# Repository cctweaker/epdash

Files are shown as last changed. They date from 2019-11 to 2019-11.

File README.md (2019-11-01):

# epdash
ESP8266 + E-paper wireless dashboard

It is a complete project, from 3D design to microcontroller program and webserver helper.

Main components are:
- the e-paper display: Waveshare 7.5 black/red display => https://www.waveshare.com/wiki/7.5inch_e-Paper_HAT_(B)
- trigBoard from Kevin Darrah: https://www.kevindarrah.com/wiki/index.php?title=TrigBoard
- EPaperBoard also from Kevin Darrah: https://www.kevindarrah.com/wiki/index.php?title=EPaperBoard
- 2 pcs. Li-Ion batteries 3500mAh each that should power this device for quite some time

Trigboard is a ESP8266 ultra low power standby device. It wakes up and powers the ESP and display and then goes back to ULP sleep. The timer can be programmed by changing a resistor and I chose one that wakes up the device once every ~30 minutes.

After waking up, the ESP connects to a intranet web server and fetches a 640x384 pixel bmp file that it then displays. After finishing, it signals the timer chip that it is done and power is removed. Countdown of a new sleep period begins.

My goal was a complete freedom to setup the display. Using the ESP to generate the display data meant always changing the programming on the chip, updating its flash and so on. Pretty cumbersome. Moving the display data creation to a local webserver and fetching just the bmp file allowed me change anything at any time, without bothering the display unit itself.

Initial project was a weather display. Data was retreived by json and set up on the ESP, total time to update the display was about 300 seconds. Now I serve just the bmp file, generated on the fly, and the update time was reduced to about 55 seconds with DHCP enabled on the ESP. Probably a few seconds less by manually assigning the IP address.

Sample output:<br>
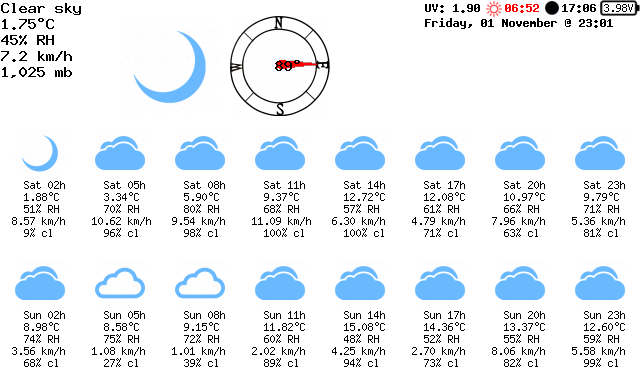
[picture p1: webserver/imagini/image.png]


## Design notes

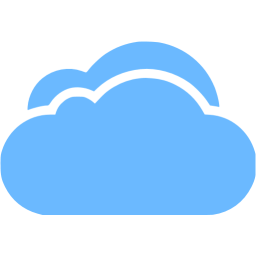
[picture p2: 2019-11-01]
webserver/meteo/04n.png

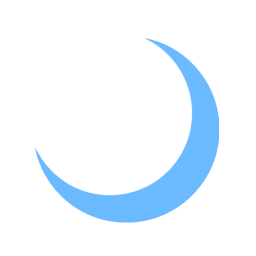
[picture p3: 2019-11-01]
webserver/meteo/01n.png

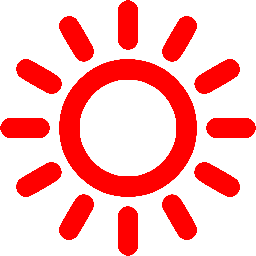
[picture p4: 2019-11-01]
webserver/meteo/01d.png

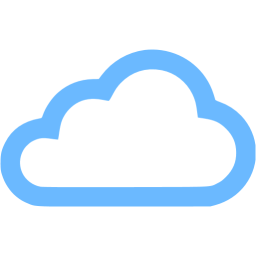
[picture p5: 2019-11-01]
webserver/meteo/03n.png

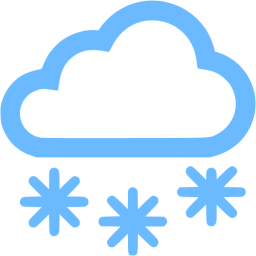
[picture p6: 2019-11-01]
webserver/meteo/13n.png

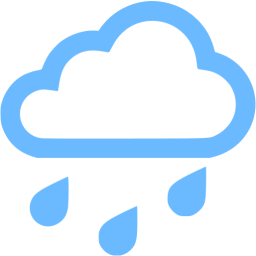
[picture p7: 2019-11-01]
webserver/meteo/09n.png

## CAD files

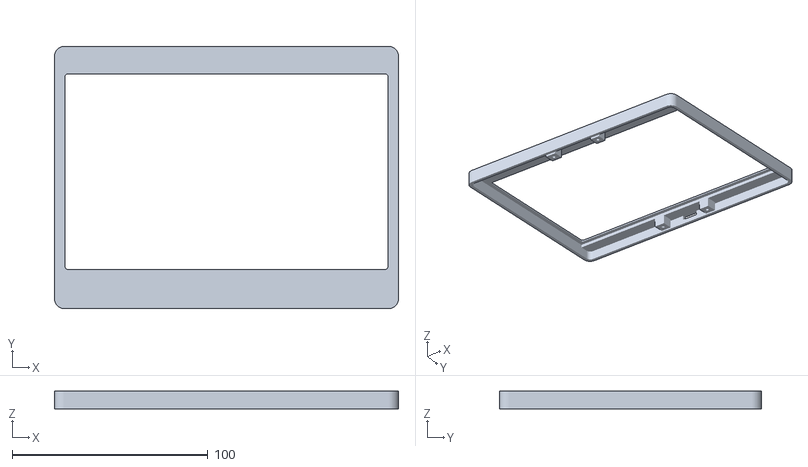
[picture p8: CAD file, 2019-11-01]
3D_case/faceplate.stl
175.8 x 134.0 x 9.00

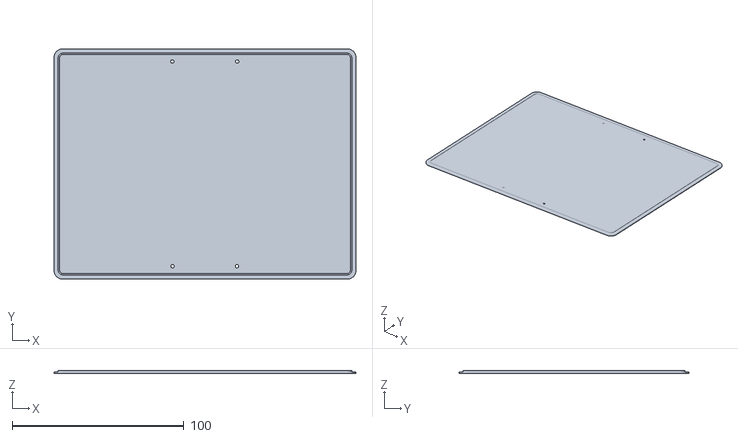
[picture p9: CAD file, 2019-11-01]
3D_case/backplate.stl
175.8 x 134.0 x 1.80

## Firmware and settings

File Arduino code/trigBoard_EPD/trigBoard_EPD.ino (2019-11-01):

// Uses GxEPD2 Library: https://github.com/ZinggJM/GxEPD2
// base class GxEPD2_GFX can be used to pass references or pointers to the display instance as parameter, uses ~1.2k more code
// enable or disable GxEPD2_GFX base class
#define ENABLE_GxEPD2_GFX 0

#include <GxEPD2_BW.h>
#include <GxEPD2_3C.h>
#include <Arduino.h>
#include <ESP8266WiFi.h>

GxEPD2_3C<GxEPD2_750c, GxEPD2_750c::HEIGHT / 4> display(GxEPD2_750c(/*CS=D8*/ 16, /*DC=D3*/ 4, /*RST=D4*/ 5, /*BUSY=D2*/ 12));

#define LEDpin 0 // this is the on-board LED - write this LOW to turn on
#define DONEpin 15  // write this PIN HIGH to kill your own power
#define EXTWAKEpin 16 // check this pin right when you boot up to see if the external switch woke you up - will be LOW if externally woken


const char* host = "127.0.0.1";
const char* path = "/webserver/";
const char* filename = "esp-en.php?b=";

const char* ESP_HOST_NAME = "ePaperOWM";
const char* WIFI_SSID     = "WIFI";
const char* WIFI_PASSWORD = "password";


float batteryVoltage;

void setup() {

  batteryVoltage = (4 - 3.5)/(712 - 621) ;
  batteryVoltage = analogRead(A0) * batteryVoltage + (4 - batteryVoltage * 712);

  Serial.begin(115200);
  Serial.println();
  Serial.println("Afisaj EPD 7.5inch");

  display.init(115200);

  connectWifi();

  test_once();
  Serial.println("BYE!");
  pinMode(DONEpin,OUTPUT);
  digitalWrite(DONEpin,HIGH);
}

void loop() {
  Serial.print(".");
  delay(10);
}


void test_once()
{
  display.setFullWindow();
  display.setRotation(0);
  showBitmapFrom_HTTP();
  display.refresh();
}








void connectWifi() {
  WiFi.begin(WIFI_SSID, WIFI_PASSWORD);
  Serial.print("Connecting to ");
  Serial.println(WIFI_SSID);
  while (WiFi.status() != WL_CONNECTED) {
    delay(500);
    Serial.print(".");
  }
  Serial.println("");
  Serial.println("WiFi connected!");
  Serial.println(WiFi.localIP());
  Serial.println();
}







static const uint16_t input_buffer_pixels = 640; // may affect performance

static const uint16_t max_row_width = 640; // for up to 7.5" display
static const uint16_t max_palette_pixels = 256; // for depth <= 8

uint8_t input_buffer[3 * input_buffer_pixels]; // up to depth 24
uint8_t output_row_mono_buffer[max_row_width / 8]; // buffer for at least one row of b/w bits
uint8_t output_row_color_buffer[max_row_width / 8]; // buffer for at least one row of color bits
uint8_t mono_palette_buffer[max_palette_pixels / 8]; // palette buffer for depth <= 8 b/w
uint8_t color_palette_buffer[max_palette_pixels / 8]; // palette buffer for depth <= 8 c/w



void showBitmapFrom_HTTP()
{

  int16_t x = 0;
  int16_t y = 0;
  bool with_color = true;
  
  WiFiClient client;
  bool connection_ok = false;
  bool valid = false; // valid format to be handled
  bool flip = true; // bitmap is stored bottom-to-top
  uint32_t startTime = millis();
  if ((x > display.width()) || (y > display.height())) return;
  Serial.println(); Serial.print("downloading file \""); Serial.print(filename);  Serial.println("\"");
  Serial.print("connecting to "); Serial.println(host);
  if (!client.connect(host, 80))
  {
    Serial.println("connection failed");
    return;
  }
  Serial.print("requesting URL: ");
  Serial.println(String("http://") + host + path + filename);
  client.print(String("GET ") + path + filename + batteryVoltage + " HTTP/1.1\r\n" +
               "Host: " + host + "\r\n" +
               "User-Agent: GxEPD2_WiFi_Example\r\n" +
               "Connection: close\r\n\r\n");
  Serial.println("request sent");
  while (client.connected())
  {
    String line = client.readStringUntil('\n');
    if (!connection_ok)
    {
      connection_ok = line.startsWith("HTTP/1.1 200 OK");
      if (connection_ok) Serial.println(line);
      //if (!connection_ok) Serial.println(line);
    }
    if (!connection_ok) Serial.println(line);
    //Serial.println(line);
    if (line == "\r")
    {
      Serial.println("headers received");
      break;
    }
  }
  if (!connection_ok) return;
  // Parse BMP header
  if (read16(client) == 0x4D42) // BMP signature
  {
    uint32_t fileSize = read32(client);
    uint32_t creatorBytes = read32(client);
    uint32_t imageOffset = read32(client); // Start of image data
    uint32_t headerSize = read32(client);
    uint32_t width  = read32(client);
    uint32_t height = read32(client);
    uint16_t planes = read16(client);
    uint16_t depth = read16(client); // bits per pixel
    uint32_t format = read32(client);
    
    Serial.println();
    Serial.println("-------");
    Serial.println(width);
    Serial.println(height);
    Serial.println(planes);
    Serial.println(depth);
    Serial.println(format);
    Serial.println("-------");
    
    uint32_t bytes_read = 7 * 4 + 3 * 2; // read so far
    if ((planes == 1) && ((format == 0) || (format == 3))) // uncompressed is handled, 565 also
    {
      Serial.print("File size: "); Serial.println(fileSize);
      Serial.print("Image Offset: "); Serial.println(imageOffset);
      Serial.print("Header size: "); Serial.println(headerSize);
      Serial.print("Bit Depth: "); Serial.println(depth);
      Serial.print("Image size: ");
      Serial.print(width);
      Serial.print('x');
      Serial.println(height);
      // BMP rows are padded (if needed) to 4-byte boundary
      uint32_t rowSize = (width * depth / 8 + 3) & ~3;
      if (depth < 8) rowSize = ((width * depth + 8 - depth) / 8 + 3) & ~3;
      if (height < 0)
      {
        height = -height;
        flip = false;
      }
      uint16_t w = width;
      uint16_t h = height;
      if ((x + w - 1) >= display.width())  w = display.width()  - x;
      if ((y + h - 1) >= display.height()) h = display.height() - y;
      if (w <= max_row_width) // handle with direct drawing
      {
        valid = true;
        uint8_t bitmask = 0xFF;
        uint8_t bitshift = 8 - depth;
        uint16_t red, green, blue;
        bool whitish, colored;
        if (depth == 1) with_color = false;
        if (depth <= 8)
        {
          if (depth < 8) bitmask >>= depth;
          bytes_read += skip(client, 54 - bytes_read); //palette is always @ 54
          for (uint16_t pn = 0; pn < (1 << depth); pn++)
          {
            blue  = client.read();
            green = client.read();
            red   = client.read();
            client.read();
            bytes_read += 4;
            whitish = with_color ? ((red > 0x80) && (green > 0x80) && (blue > 0x80)) : ((red + green + blue) > 3 * 0x80); // whitish
            colored = (red > 0xF0) || ((green > 0xF0) && (blue > 0xF0)); // reddish or yellowish?
            if (0 == pn % 8) mono_palette_buffer[pn / 8] = 0;
            mono_palette_buffer[pn / 8] |= whitish << pn % 8;
            if (0 == pn % 8) color_palette_buffer[pn / 8] = 0;
            color_palette_buffer[pn / 8] |= colored << pn % 8;
          }
        }
        uint32_t rowPosition = flip ? imageOffset + (height - h) * rowSize : imageOffset;
        //Serial.print("skip "); Serial.println(rowPosition - bytes_read);
        bytes_read += skip(client, rowPosition - bytes_read);
        for (uint16_t row = 0; row < h; row++, rowPosition += rowSize) // for each line
        {
          if (!connection_ok || !(client.connected() || client.available())) break;
          yield(); //delay(1); // yield() to avoid WDT
          uint32_t in_remain = rowSize;
          uint32_t in_idx = 0;
          uint32_t in_bytes = 0;
          uint8_t in_byte = 0; // for depth <= 8
          uint8_t in_bits = 0; // for depth <= 8
          uint8_t out_byte = 0xFF; // white (for w%8!=0 boarder)
          uint8_t out_color_byte = 0xFF; // white (for w%8!=0 boarder)
          uint32_t out_idx = 0;
          for (uint16_t col = 0; col < w; col++) // for each pixel
          {
            yield();
            if (!connection_ok || !(client.connected() || client.available())) break;
            // Time to read more pixel data?
            if (in_idx >= in_bytes) // ok, exact match for 24bit also (size IS multiple of 3)
            {
              uint32_t get = in_remain > sizeof(input_buffer) ? sizeof(input_buffer) : in_remain;
              uint32_t got = read(client, input_buffer, get);
              while ((got < get) && connection_ok)
              {
                //Serial.print("got "); Serial.print(got); Serial.print(" < "); Serial.print(get); Serial.print(" @ "); Serial.println(bytes_read);
                //if ((get - got) > client.available()) delay(200); // does improve? yes, if >= 200
                uint32_t gotmore = read(client, input_buffer + got, get - got);
                got += gotmore;
                connection_ok = gotmore > 0;
              }
              in_bytes = got;
              in_remain -= got;
              bytes_read += got;
            }
            if (!connection_ok)
            {
              Serial.print("Error: got no more after "); Serial.print(bytes_read); Serial.println(" bytes read!");
              break;
            }
            switch (depth)
            {
              case 24:
                blue = input_buffer[in_idx++];
                green = input_buffer[in_idx++];
                red = input_buffer[in_idx++];
                whitish = with_color ? ((red > 0x80) && (green > 0x80) && (blue > 0x80)) : ((red + green + blue) > 3 * 0x80); // whitish
                colored = (red > 0xF0) || ((green > 0xF0) && (blue > 0xF0)); // reddish or yellowish?
                break;
              case 16:
                {
                  uint8_t lsb = input_buffer[in_idx++];
                  uint8_t msb = input_buffer[in_idx++];
                  if (format == 0) // 555
                  {
                    blue  = (lsb & 0x1F) << 3;
                    green = ((msb & 0x03) << 6) | ((lsb & 0xE0) >> 2);
                    red   = (msb & 0x7C) << 1;
                  }
                  else // 565
                  {
                    blue  = (lsb & 0x1F) << 3;
                    green = ((msb & 0x07) << 5) | ((lsb & 0xE0) >> 3);
                    red   = (msb & 0xF8);
                  }
                  whitish = with_color ? ((red > 0x80) && (green > 0x80) && (blue > 0x80)) : ((red + green + blue) > 3 * 0x80); // whitish
                  colored = (red > 0xF0) || ((green > 0xF0) && (blue > 0xF0)); // reddish or yellowish?
                }
                break;
              case 1:
              case 4:
              case 8:
                {
                  if (0 == in_bits)
                  {
                    in_byte = input_buffer[in_idx++];
                    in_bits = 8;
                  }
                  uint16_t pn = (in_byte >> bitshift) & bitmask;
                  whitish = mono_palette_buffer[pn / 8] & (0x1 << pn % 8);
                  colored = color_palette_buffer[pn / 8] & (0x1 << pn % 8);
                  in_byte <<= depth;
                  in_bits -= depth;
                }
                break;
            }
            if (whitish)
            {
              // keep white
            }
            else if (colored && with_color)
            {
              out_color_byte &= ~(0x80 >> col % 8); // colored
            }
            else
            {
              out_byte &= ~(0x80 >> col % 8); // black
            }
            if ((7 == col % 8) || (col == w - 1)) // write that last byte! (for w%8!=0 boarder)
            {
              output_row_color_buffer[out_idx] = out_color_byte;
              output_row_mono_buffer[out_idx++] = out_byte;
              out_byte = 0xFF; // white (for w%8!=0 boarder)
              out_color_byte = 0xFF; // white (for w%8!=0 boarder)
            }
          } // end pixel
          int16_t yrow = y + (flip ? h - row - 1 : row);
          display.writeImage(output_row_mono_buffer, output_row_color_buffer, x, yrow, w, 1);
        } // end line
        Serial.print("downloaded in "); Serial.print(millis() - startTime); Serial.println(" ms");
        Serial.print("bytes read "); Serial.println(bytes_read);
      }
    }
  }
  if (!valid)
  {
    Serial.println("bitmap format not handled.");
  }
}




uint32_t skip(WiFiClient& client, int32_t bytes)
{
  int32_t remain = bytes;
  uint32_t start = millis();
  while ((client.connected() || client.available()) && (remain > 0))
  {
    if (client.available())
    {
      int16_t v = client.read();
      remain--;
    }
    else delay(1);
    if (millis() - start > 2000) break; // don't hang forever
  }
  return bytes - remain;
}


uint32_t read(WiFiClient& client, uint8_t* buffer, int32_t bytes)
{
  int32_t remain = bytes;
  uint32_t start = millis();
  while ((client.connected() || client.available()) && (remain > 0))
  {
    if (client.available())
    {
      int16_t v = client.read();
      *buffer++ = uint8_t(v);
      remain--;
    }
    else delay(1);
    if (millis() - start > 2000) break; // don't hang forever
  }
  return bytes - remain;
}



uint16_t read16(WiFiClient& client)
{
  // BMP data is stored little-endian, same as Arduino.
  uint16_t result;
  ((uint8_t *)&result)[0] = client.read(); // LSB
  ((uint8_t *)&result)[1] = client.read(); // MSB
  return result;
}

uint32_t read32(WiFiClient& client)
{
  // BMP data is stored little-endian, same as Arduino.
  uint32_t result;
  ((uint8_t *)&result)[0] = client.read(); // LSB
  ((uint8_t *)&result)[1] = client.read();
  ((uint8_t *)&result)[2] = client.read();
  ((uint8_t *)&result)[3] = client.read(); // MSB
  return result;
}
